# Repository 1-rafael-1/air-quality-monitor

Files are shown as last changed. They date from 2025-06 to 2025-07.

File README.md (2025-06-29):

# Air Quality Monitor

A compact, battery-powered air quality monitoring device built with Rust and a Waveshare RP2350-based board. This device continuously monitors air quality, temperature, and humidity with a small OLED display.

**⚠️ Educational Project Notice**: This is a hobby project developed for educational purposes only.

## Finished Device

<table>
<tr>
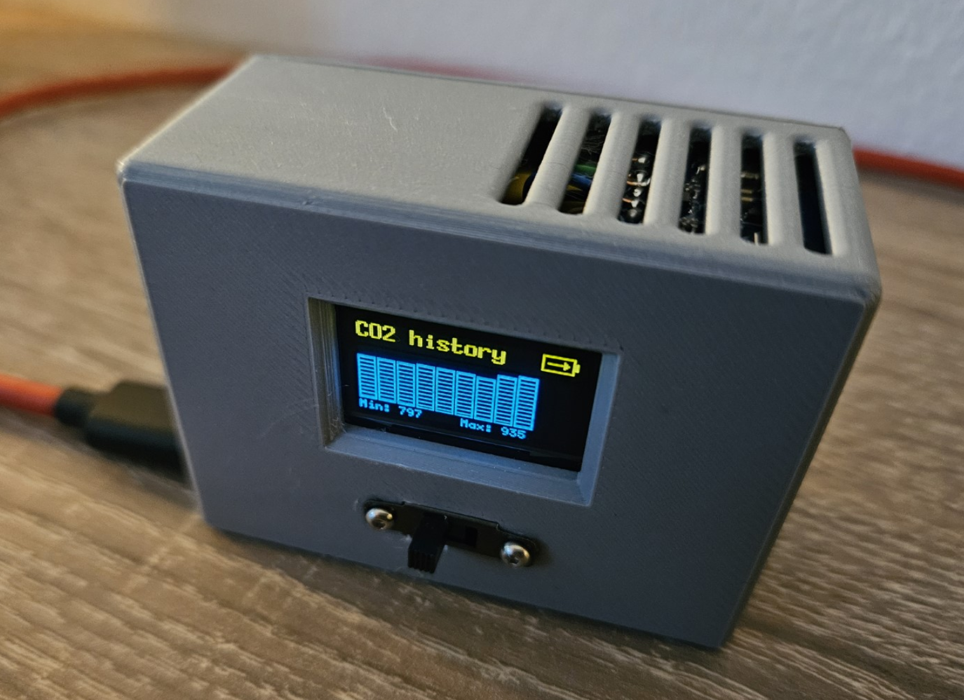
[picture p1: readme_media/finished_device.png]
Finished Air Quality Monitor Device
<td></td>
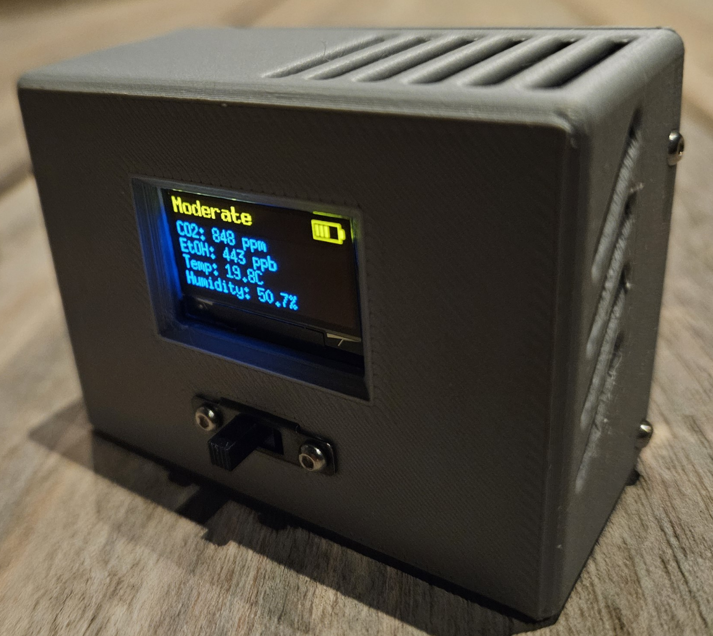
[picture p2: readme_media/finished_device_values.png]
Device Display Showing Values
<td></td>
</tr>
</table>

## How It Works

1. **Sensor Reading**: Collects data from ENS160 (air quality) and AHT21 (temperature/humidity) sensors every 5 minutes
2. **Data Processing**: Uses median filtering on air quality readings to reduce noise
3. **Display Updates**: Shows current readings and battery status on a 128x64 OLED display, changing between data and bar graph views every 10 seconds
4. **Power Management**: Reduced clock speed (18MHz) and core voltage to conserve power.
5. **Battery Monitoring**: VSYS voltage is measured every 4 seconds to determine battery level and charging state. Uses moving median filtering (5 samples) when on battery power for stable readings, and direct measurements when charging to reduce latency.

## Components

| Component | Description | Purpose |
|---|---|---|
| Waveshare RP2350 Board | RP2350-based development board. There are cheaper alternatives available on AliExpress, so long as they have the Pico 2 form factor and a battery connector with charger it should be fine | Core processing and I/O |
| ENS160 + AHT21 Module | Combined air quality and temperature/humidity sensor board. There are cheap combined boards available | Environmental monitoring |
| SSD1306 | 128x64 OLED Display, yellow/blue in my case here but monochrome or blue will work just as well | Data visualization |
| LiPo Battery | 3.7V rechargeable battery. I use 2500mAh, 7 x 40 x 60mm with a 1.25mm connector | Portable power source |
| Slide Switch | Slide switch to control power | Power management |

### Things to know

The ENS160 sensor and AHT21 sensor are on a combined board here, bought very cheap. An ENS160 datasheet and the ENS160 sensor on the board do not always agree on things. The AHT21 may in fact be an AHT20 according to some comments...

Here is what I found not being what I expected:

+ ENS160 ADD pin seems to be floating, sensor will not work if not connected to GND
+ Vendor says 1min warmup time, datasheet says 3min warmup time for ENS160.
+ ENS160 datasheet specifies `InitialStartupPhase` during the first 1 hour of operation and after 24h the sensor should save that it will never need this again. I find this not to be the case, that way all ideas of elaborate power management and sleep/wake cycles are out of the window. The sensor needs to be continuously powered to provide reliable readings.
+ AHT21 humidity is always reasonably close to external sensor readings, but temperature is always 2 to 3 degrees Celsius above external sensor readings. I just introduced a correction factor in code. I suppose this is due to the sensor being on the same board as the ENS160, which generates heat during operation.

Bottom line: You buy cheap, you get cheap.

## Hardware Connections

Connect the components to the Waveshare RP2350 board as follows:

### I2C Bus (Shared)

All I2C devices (ENS160 + AHT21 module and SSD1306 display) connect to the same I2C bus.
Since ENS160 and AHT21 are on the same module, they share the bus anyway and the SSD1306 display is also connected to the same I2C bus for simplicity.

### ENS160 + AHT21 Module

+ **VCC**: 3.3V
+ **GND**: Ground
+ **SDA**: GPIO 16
+ **SCL**: GPIO 17
+ **INT**: GPIO 18 (ENS160 interrupt pin)

### SSD1306 OLED Display

+ **VCC**: 3.3V
+ **GND**: Ground
+ **SDA**: GPIO 16
+ **SCL**: GPIO 17

### Power Monitoring

The Waveshare board has a battery connector, that is wired to vsys, so not need for connections beside plugging in the battery.

Power and charging detection is handled through VSYS voltage monitoring due to RP2350 E9 erratum affecting VBUS detection.

### Battery

+ **Battery**: 3.7V LiPo battery connected to the battery connector on the Waveshare board.

The Waveshare board has built-in battery charging and power management, so no additional components are required.
In case you want to use i.e. a Pi Pico 2, you need to add a charger board and appropriate circuit. The Pi Pico 2 datasheet has instructions.

## Power Consumption

On average I measure around 39mA current consumption when supplying 3.7V to the device (which is the nominal voltage for the battery I use).

The baseline for controller and display combined is around 10-11mA, the ENS160 sensor draws around 28mA when operating continuously in Standard mode, the AHT21 is negligible. With these values the device can theoretically run for around 65 hours on a 2500mAh battery, considering the built-in charge controller of the battery will not let us use more than say 90% of the battery capacity.

Sleep/wake cycling was initially attempted to reduce power consumption, but proved unreliable (see above).

## Assembly and Enclosure

### Electronics Assembly

Wire the components according to the hardware connections above. For the slide switch, cut the ground wire of the battery connector and connect it to the switch.

<table>
<tr>
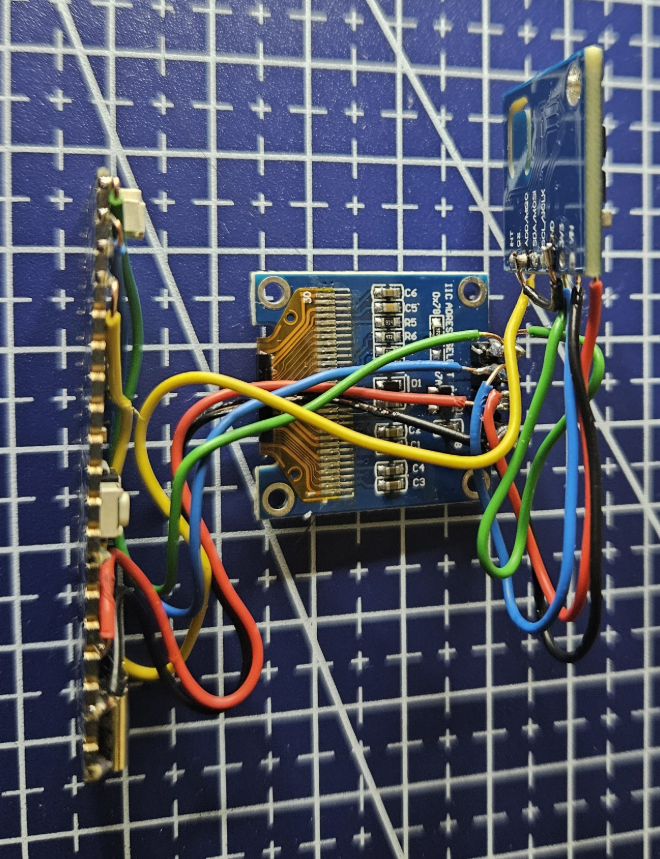
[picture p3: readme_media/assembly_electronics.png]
Electronics Assembly
<td></td>
</tr>
</table>

### 3D-Printed Enclosure

The device features a custom 3D-printed enclosure.

**3D Print Files**: All enclosure files are available in the [`enclosure/`](./enclosure/) directory:

+ `Main Body.3mf` - Main housing with sensor openings
+ `Back Lid.3mf` - Battery compartment cover
+ `EnclosureComplete.FCStd` - Body FreeCAD file
+ `Back Lid.FCStd` - Back lid FreeCAD file

<table>
<tr>
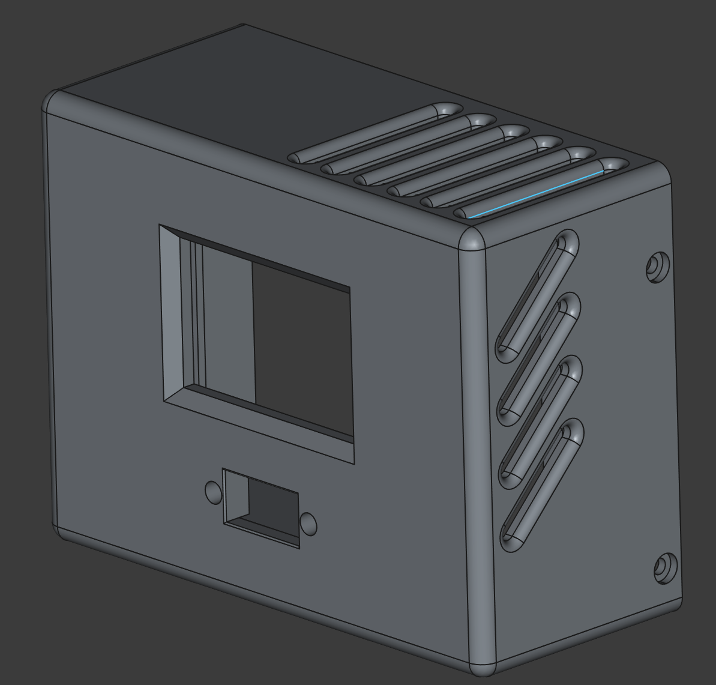
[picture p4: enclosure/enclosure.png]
3D Printed Enclosure
<td></td>
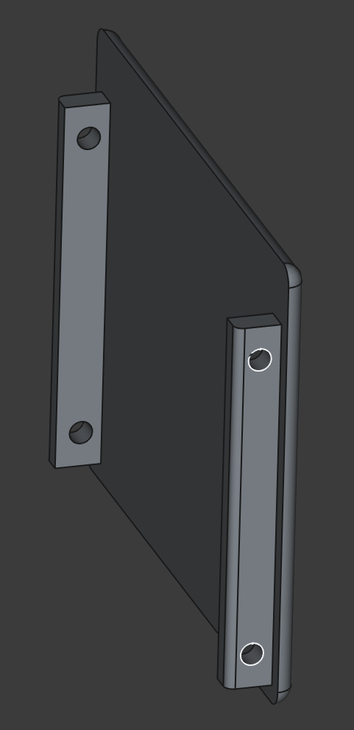
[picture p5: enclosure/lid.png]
Enclosure Lid Detail
<td></td>
</tr>
</table>

### Enclosure Assembly

After printing the enclosure parts, assemble the electronics into the housing. The main body provides openings for sensor airflow while protecting the internal components.

<table>
<tr>
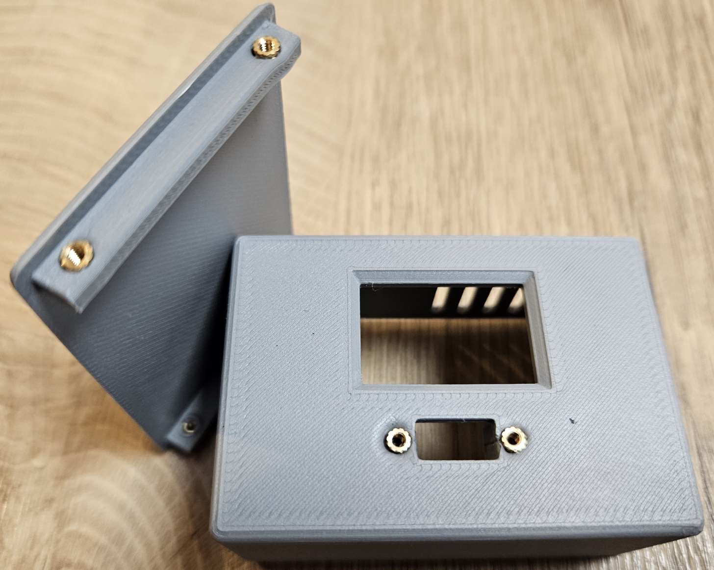
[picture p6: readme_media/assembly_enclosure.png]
Enclosure Assembly Process
<td></td>
</tr>
</table>

Use brass hot melt inserts for the enclosure screws to secure the back lid. Same goes for the slide switch, which is mounted on the front side of the enclosure.

The whole electronics can be fitted inside without any glue, only the OLED display needs held in place by tape (because i forgot to design a holder for it).

<table>
<tr>
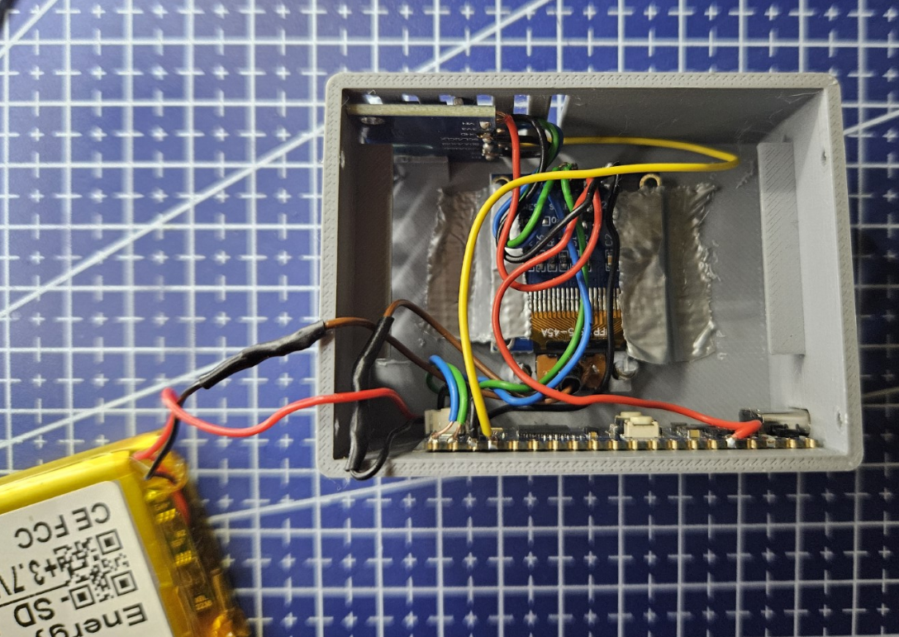
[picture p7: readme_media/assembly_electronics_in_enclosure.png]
Enclosure Assembly Process 2
<td></td>
</tr>
</table>

## Code Structure

The firmware is built using Embassy (async Rust) and organized into modular tasks:

```text
src/
├── main.rs          # Entry point, hardware initialization, task spawning
├── sensor.rs        # ENS160 and AHT21 sensor data acquisition
├── display.rs       # SSD1306 OLED display management and UI rendering
├── event.rs         # Inter-task communication events
├── orchestrate.rs   # Main control loop and data coordination
├── system_state.rs  # System state management (battery, sensor data, display modes)
├── vsys.rs          # Battery voltage monitoring and charging detection
├── watchdog.rs      # System watchdog
└── media/           # Bitmap assets for display (battery icons, etc.)
```

### Key Features

+ **Async Architecture**: Uses Embassy framework for task scheduling
+ **Power Optimization**: 18MHz clock, voltage scaling, and idle modes
+ **Median Filtering**: Reduces sensor noise through statistical processing
+ **Battery Monitoring**: VSYS-based voltage tracking with adaptive filtering (median filtering on battery, direct measurement when charging)
+ **Charging Detection**: Automatic detection of charging state via voltage thresholds (works around RP2350 E9 erratum)
+ **Mode Switching**: Automatic display cycling between sensor data and CO2 history views
+ **Watchdog System**: Monitors task health with 15-minute timeout and automatic system reset on failure

## Building and Flashing

```bash
# Build for release (optimized for size and power)
cargo build --release

# Option 1: Flash directly with picotool (elf2uf2-rs does not support RP2350 as of 06.2025)
# Put board in bootloader mode (hold BOOTSEL while connecting USB)
picotool load -u -v -x -t elf target/thumbv8m.main-none-eabihf/release/air-quality-monitor

# Option 2: Convert to UF2 and copy manually
picotool uf2 convert target/thumbv8m.main-none-eabihf/release/air-quality-monitor -t elf air-quality-monitor.uf2 -t uf2
# Copy the resulting .uf2 file to the RP2350 board in bootloader mode
```

For development builds probe-rs can be used:

```bash
# Build for development
cargo build
# Flash using probe-rs
cargo run
```

## License

This project is licensed under either of:

+ [Apache License, Version 2.0](LICENSE-APACHE)
+ [MIT License](LICENSE-MIT)

at your option.

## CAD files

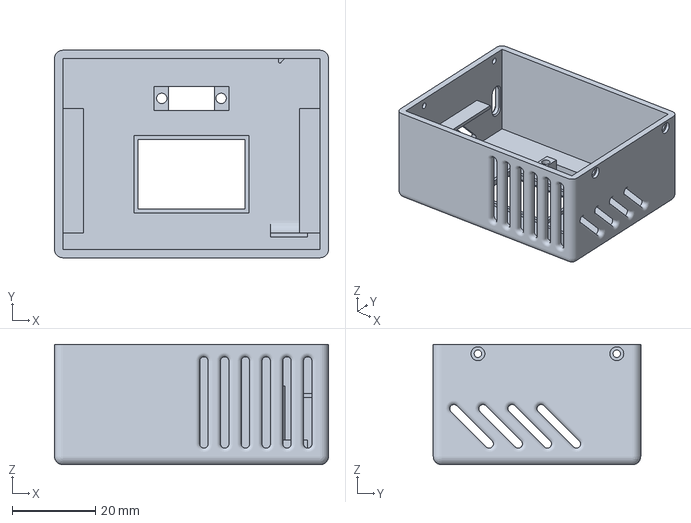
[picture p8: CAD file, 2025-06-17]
enclosure/Main Body.3mf
66.0 x 50.0 x 29.0 mm

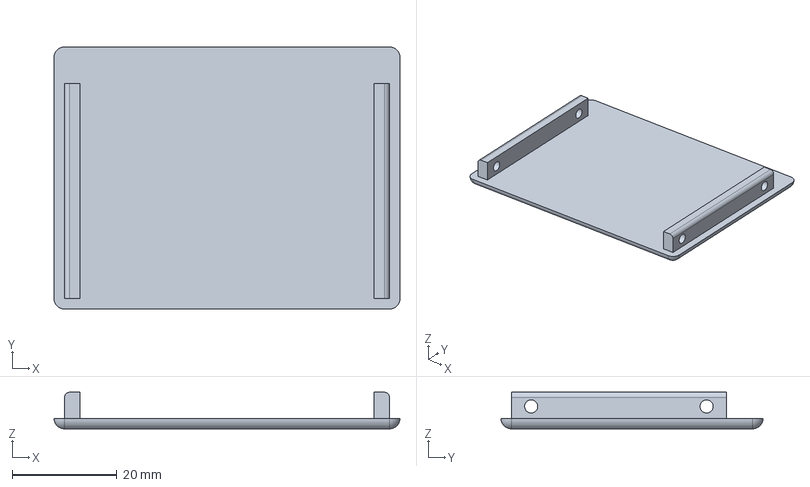
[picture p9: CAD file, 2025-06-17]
enclosure/Back Lid.FCStd
66.0 x 50.0 x 7.00 mm

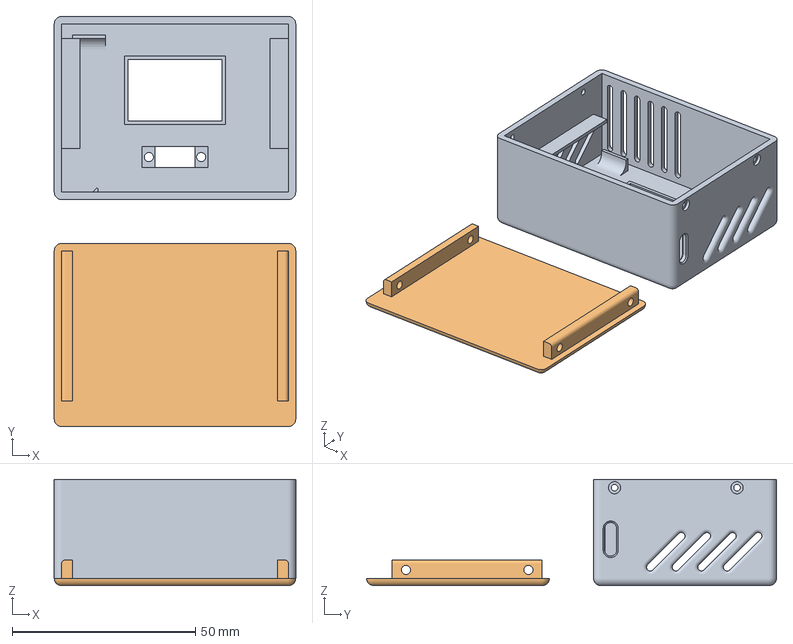
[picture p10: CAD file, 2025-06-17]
enclosure/Bambu Studio Print Project.3mf
66.0 x 112.0 x 29.0 mm

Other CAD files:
enclosure/EnclosureComplete.FCStd
enclosure/Back Lid.3mf

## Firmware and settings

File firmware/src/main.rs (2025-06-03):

#![no_std]
#![no_main]

use aht20_async::Aht20;
use defmt::{Debug2Format, info};
use defmt_rtt as _;
use embassy_embedded_hal::shared_bus::asynch::i2c::I2cDevice;
use embassy_executor::Spawner;
use embassy_rp::{
    bind_interrupts,
    block::ImageDef,
    config::Config,
    gpio::{Input, Pull},
    i2c::{Async, Config as I2cConfig, I2c, InterruptHandler},
    peripherals::{I2C0, PIN_18},
};
use embassy_sync::{blocking_mutex::raw::NoopRawMutex, mutex::Mutex};
use embassy_time::{Delay, Timer};
use ens160_aq::{
    Ens160,
    data::{InterruptPinConfig, OperationMode, ValidityFlag},
};
use panic_probe as _;
use static_cell::StaticCell;

// Firmware image type for bootloader
#[unsafe(link_section = ".start_block")]
#[used]
pub static IMAGE_DEF: ImageDef = ImageDef::secure_exe();

bind_interrupts!(struct Irqs {
        I2C0_IRQ => InterruptHandler<I2C0>;
    }
);

#[embassy_executor::main]
async fn main(_spawner: Spawner) {
    let p = embassy_rp::init(Config::default());

    // I2C setup
    let sda = p.PIN_16;
    let scl = p.PIN_17;
    let i2c0 = p.I2C0;
    let i2c = I2c::new_async(i2c0, scl, sda, Irqs, I2cConfig::default());
    static I2C_BUS: StaticCell<Mutex<NoopRawMutex, I2c<'static, I2C0, Async>>> = StaticCell::new();
    let i2c_bus = I2C_BUS.init(Mutex::new(i2c));
    let i2c_device_aht21 = I2cDevice::new(i2c_bus);
    let i2c_device_ens160 = I2cDevice::new(i2c_bus);

    // Initialize AHT20 and calibrate it
    let mut aht21 = Aht20::new(i2c_device_aht21, Delay).await.unwrap();
    info!("calibrate aht21");
    let _ = aht21.calibrate().await.unwrap();
    Timer::after_millis(5000).await;
    info!("done calibrating");

    // Initialize ENS160
    let mut ens160 = Ens160::new(i2c_device_ens160, Delay);
    let mut ens160_int = Input::new(p.PIN_18, Pull::Up);

    // In the loop, we read the AHT20 sensor and then use the ENS160 to get air quality data.
    loop {
        let (temp, rh) = {
            let (hum, temp) = aht21.read().await.unwrap();
            info!("Temperature: {}°C, Humidity: {}%", temp.celsius(), hum.rh());
            (temp.celsius(), hum.rh())
        };

        {
            match ens160.initialize().await {
                Ok(_) => {}
                Err(e) => {
                    info!("Failed to initialize ENS160: {}", Debug2Format(&e));
                    return;
                }
            };
            // ens160.clear_command().await.unwrap();
            ens160.set_operation_mode(OperationMode::Standard).await.unwrap();

            let mut status = ens160.get_status().await.unwrap();
            while !matches!(status.validity_flag(), ValidityFlag::NormalOperation) {
                info!("ENS160 is not in normal operation mode, waiting...");
                Timer::after_millis(1000).await;
                status = ens160.get_status().await.unwrap();
                info!("ENS160 status: {}", Debug2Format(&status));
            }

            ens160.set_temp_rh_comp(temp, rh as u16).await.unwrap();

            info!("ENS160 status: {}", Debug2Format(&status));

            let config = InterruptPinConfig::builder()
                .active_low()
                .enable_interrupt()
                .on_new_data()
                // .on_new_group_data()
                .build();

            info!("Configuring ENS160 interrupt pin: {}", config);

            ens160.config_interrupt_pin(config).await.unwrap();

            ens160.config_interrupt_pin(0x23).await.unwrap();
            Timer::after_millis(20).await;

            let status = ens160.get_status().await.unwrap();
            info!("ENS160 status: {}", Debug2Format(&status));

            // wait for ENS160 to have data ready
            info!("is low: {}", ens160_int.is_low());
            ens160_int.wait_for_low().await;
            info!("is low: {}", ens160_int.is_low());

            let status = ens160.get_status().await.unwrap();
            info!("ENS160 status: {}", Debug2Format(&status));

            // Timer::after_millis(1000).await;

            let eco2 = ens160.get_eco2().await.unwrap();
            let aq = ens160.get_airquality_index().await.unwrap();
            let h = ens160.get_etoh().await.unwrap();
            info!(
                "Air Quality Index: {}, eCO2: {} ppm, Ethanol: {} ppb",
                Debug2Format(&aq),
                eco2.get_value(),
                h,
            );
            ens160.set_operation_mode(OperationMode::Sleep).await.unwrap();
        } // drop ens160, but keep i2c_bus

        Timer::after_secs(10).await;
    }
}

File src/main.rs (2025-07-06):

//! RP2350 based air quality monitor firmware
//!
//! Uses ens160 for air quality, AHT21 for temperature and humidity, and SSD1306 for display.

#![no_std]
#![no_main]

/// Firmware version string
pub const FIRMWARE_VERSION: &str = concat!("v", env!("CARGO_PKG_VERSION"));

use defmt_rtt as _;
use embassy_embedded_hal::shared_bus::asynch::i2c::I2cDevice;
use embassy_executor::Spawner;
use embassy_rp::{
    adc::InterruptHandler as AdcInterruptHandler,
    bind_interrupts,
    block::ImageDef,
    clocks::{ClockConfig, CoreVoltage},
    config::Config,
    gpio::{Input, Pull},
    i2c::{Async, Config as I2cConfig, I2c, InterruptHandler},
    peripherals::I2C0,
};
use embassy_sync::{blocking_mutex::raw::NoopRawMutex, mutex::Mutex};
use panic_probe as _;
use static_cell::StaticCell;

mod display;
mod event;
mod humidity_calibrator;
mod orchestrate;
mod sensor;
mod system_state;
mod vsys;
mod watchdog;

// Firmware image type for bootloader
#[unsafe(link_section = ".start_block")]
#[used]
pub static IMAGE_DEF: ImageDef = ImageDef::secure_exe();

bind_interrupts!(struct Irqs {
        I2C0_IRQ => InterruptHandler<I2C0>;
        ADC_IRQ_FIFO => AdcInterruptHandler;
    }
);

#[embassy_executor::main]
async fn main(spawner: Spawner) {
    #[allow(clippy::unwrap_used)]
    // Reduce the clock speed to conserve power
    let mut config = Config::new(ClockConfig::system_freq(18_000_000).unwrap());
    config.clocks.core_voltage = CoreVoltage::V0_90;
    let p = embassy_rp::init(config);

    // I2C setup
    let sda = p.PIN_16;
    let scl = p.PIN_17;
    let i2c0 = p.I2C0;
    let i2c = I2c::new_async(i2c0, scl, sda, Irqs, I2cConfig::default());
    static I2C_BUS: StaticCell<Mutex<NoopRawMutex, I2c<'static, I2C0, Async>>> = StaticCell::new();
    let i2c_bus = I2C_BUS.init(Mutex::new(i2c));

    // Initialize the I2C devices
    let i2c_device_aht21 = I2cDevice::new(i2c_bus);
    let i2c_device_ens160 = I2cDevice::new(i2c_bus);
    let i2c_device_ssd1306 = I2cDevice::new(i2c_bus);

    // Initialize the interrupt pin for ENS160
    let ens160_int = Input::new(p.PIN_18, Pull::Up);

    // And spawn the tasks
    #[allow(clippy::unwrap_used)]
    spawner
        .spawn(sensor::sensor_task(i2c_device_aht21, i2c_device_ens160, ens160_int))
        .unwrap();
    #[allow(clippy::unwrap_used)]
    spawner.spawn(display::display_task(i2c_device_ssd1306)).unwrap();
    #[allow(clippy::unwrap_used)]
    spawner.spawn(display::mode_switch_task()).unwrap();
    #[allow(clippy::unwrap_used)]
    spawner.spawn(watchdog::watchdog_task(p.WATCHDOG)).unwrap();
    #[allow(clippy::unwrap_used)]
    spawner.spawn(orchestrate::orchestrate_task()).unwrap();
    #[allow(clippy::unwrap_used)]
    spawner.spawn(vsys::vsys_voltage_task(p.ADC, p.PIN_29)).unwrap();
}

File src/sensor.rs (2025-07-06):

//! Sensor task for reading data from AHT21 and ENS160 sensors.
use aht20_async::Aht20;
use defmt::{Debug2Format, info};
use embassy_embedded_hal::shared_bus::asynch::i2c::I2cDevice;
use embassy_rp::{
    gpio::Input,
    i2c::{Async, I2c},
    peripherals::I2C0,
};
use embassy_sync::blocking_mutex::raw::NoopRawMutex;
use embassy_time::{Delay, Timer};
use ens160_aq::{
    Ens160,
    data::{AirQualityIndex, InterruptPinConfig},
};
use heapless::Vec;
use moving_median::MovingMedian;
use panic_probe as _;

use crate::{
    event::{Event, send_event},
    humidity_calibrator::HumidityCalibrator,
    watchdog::{TaskId, report_task_failure, report_task_success},
};

/// Temperature offset for AHT21 sensor in degrees Celsius
static AHT21_TEMPERATURE_OFFSET: f32 = -3.5;

/// Warmup time for ENS160 sensor in seconds
const WARMUP_TIME: u64 = 180;

/// Read interval for continuous operation (5 minutes)
const READ_INTERVAL: u64 = 300;

/// Number of readings for ENS160 median calculation
const ENS160_MEDIAN_READINGS: usize = 3;

/// Initialize the AHT21 sensor
async fn initialize_aht21(
    aht21_device: I2cDevice<'static, NoopRawMutex, I2c<'static, I2C0, Async>>,
) -> Option<Aht20<I2cDevice<'static, NoopRawMutex, I2c<'static, I2C0, Async>>, Delay>> {
    let mut aht21 = Aht20::new(aht21_device, Delay).await.ok()?;
    Timer::after_millis(100).await;
    info!("calibrate aht21");
    aht21.calibrate().await.ok()?;
    info!("AHT21 calibration successful");
    Timer::after_millis(1000).await;
    Some(aht21)
}

/// Initialize the ENS160 sensor
async fn initialize_ens160(
    ens160_device: I2cDevice<'static, NoopRawMutex, I2c<'static, I2C0, Async>>,
) -> Option<Ens160<I2cDevice<'static, NoopRawMutex, I2c<'static, I2C0, Async>>, Delay>> {
    let mut ens160 = Ens160::new(ens160_device, Delay);

    if let Err(e) = ens160.initialize().await {
        info!(
            "Failed to initialize ENS160: {} - triggering system reset",
            Debug2Format(&e)
        );
        return None;
    }
    info!("ENS160 initialized successfully");

    Some(ens160)
}

/// Struct to hold AHT21 sensor readings
struct Aht21Readings {
    /// Raw temperature in degrees Celsius (for ENS160 compensation)
    raw_temperature: f32,
    /// Display temperature in degrees Celsius (with offset applied)
    display_temperature: f32,
    /// Raw humidity in percentage (uncalibrated)
    raw_humidity: f32,
    /// Calibrated humidity in percentage
    calibrated_humidity: f32,
}

/// Struct to hold ENS160 sensor readings
struct Ens160Readings {
    /// eCO2 level in ppm
    co2: f32,
    /// Ethanol (TVOC) level in ppb
    etoh: f32,
    /// Air quality index data
    air_quality: AirQualityIndex,
}

/// Read data from AHT21 sensor
async fn read_aht21(
    aht21: &mut Aht20<I2cDevice<'static, NoopRawMutex, I2c<'static, I2C0, Async>>, Delay>,
    humidity_calibrator: &mut HumidityCalibrator,
) -> Result<Aht21Readings, &'static str> {
    let (hum, temp) = aht21.read().await.map_err(|_| "Failed to read AHT21 sensor")?;
    let raw_temp = temp.celsius();
    let raw_rh = hum.rh();

    // Add measurement to calibrator for learning (this also detects rapid changes)
    humidity_calibrator.add_measurement(raw_temp, raw_rh);

    // Apply calibration (this preserves rapid changes while applying offset corrections)
    let calibrated_rh = humidity_calibrator.calibrate_humidity(raw_temp, raw_rh);

    let readings = Aht21Readings {
        raw_temperature: raw_temp,
        display_temperature: raw_temp + AHT21_TEMPERATURE_OFFSET,
        raw_humidity: raw_rh,
        calibrated_humidity: calibrated_rh,
    };

    let (is_calibrated, baseline_offset, statistical_offset, sample_count, in_rapid_change, long_term_count) =
        humidity_calibrator.get_calibration_info();
    let calibration_status = if !is_calibrated {
        "ESTABLISHING_BASELINE"
    } else if in_rapid_change {
        if humidity_calibrator.baseline_shifted {
            "BASELINE_SHIFT"
        } else {
            "RAPID_CHANGE"
        }
    } else {
        "HYBRID_DRIFT_CORRECTION"
    };

    info!(
        "Temperature: {}°C (raw: {}°C), Humidity: {}% -> {}% (raw->cal), Calibration: {} (baseline offset: {}, statistical offset: {}, samples: {}, long-term count: {})",
        readings.display_temperature,
        readings.raw_temperature,
        readings.raw_humidity,
        readings.calibrated_humidity,
        calibration_status,
        baseline_offset,
        statistical_offset,
        sample_count,
        long_term_count
    );

    Ok(readings)
}

/// Read data from ENS160 sensor
/// Uses moving median of 3 readings taken, using interrupt to ensure complete data
/// Note: Temperature and humidity compensation should be set separately using `set_ens160_compensation`
async fn read_ens160(
    ens160: &mut Ens160<I2cDevice<'static, NoopRawMutex, I2c<'static, I2C0, Async>>, Delay>,
    int: &mut Input<'static>,
) -> Result<Ens160Readings, &'static str> {
    let mut co2_median = MovingMedian::<f32, ENS160_MEDIAN_READINGS>::new();
    let mut etoh_median = MovingMedian::<f32, ENS160_MEDIAN_READINGS>::new();
    let mut co2_aqi_pairs: Vec<(f32, AirQualityIndex), ENS160_MEDIAN_READINGS> = Vec::new();

    for i in 0..ENS160_MEDIAN_READINGS {
        info!("ENS160 reading {} of {}", i + 1, ENS160_MEDIAN_READINGS);

        // Wait for interrupt to ensure sensor has new data ready
        int.wait_for_low().await;
        info!("ENS160 interrupt received - data ready");

        let status = ens160.get_status().await.map_err(|_| "Failed to get ENS160 status")?;
        info!("ENS160 status: {}", Debug2Format(&status));

        let eco2 = ens160.get_eco2().await.map_err(|_| "Failed to get eCO2")?;
        let etoh = ens160.get_etoh().await.map_err(|_| "Failed to get ethanol")?;
        let aq = ens160
            .get_airquality_index()
            .await
            .map_err(|_| "Failed to get Air Quality Index")?;

        let co2_value = f32::from(eco2.get_value());
        let etoh_value = f32::from(etoh);

        info!(
            "Reading {}: Air Quality Index: {}, eCO2: {} ppm, Ethanol: {} ppb",
            i + 1,
            Debug2Format(&aq),
            co2_value,
            etoh_value
        );

        co2_median.add_value(co2_value);
        etoh_median.add_value(etoh_value);
        let _ = co2_aqi_pairs.push((co2_value, aq));
    }

    let median_co2 = co2_median.median();

    // Find the AQI that corresponds to the CO2 value closest to the median
    let air_quality = co2_aqi_pairs
        .iter()
        .min_by(|(co2_a, _), (co2_b, _)| {
            let diff_a = (co2_a - median_co2).abs();
            let diff_b = (co2_b - median_co2).abs();
            diff_a.partial_cmp(&diff_b).unwrap_or(core::cmp::Ordering::Equal)
        })
        .map(|(_, aqi)| *aqi)
        .ok_or("No CO2-AQI pairs available")?;
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

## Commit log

2025-05-29 i2c perm initialized
2025-06-03 initial stuff
    [Enclosure-Body.3mf, Enclosure-Bottom.3mf, Enclosure-Lid.3mf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]
2025-06-07 refactor: enhance project structure and documentation
    - Updated Cargo.toml with new metadata including name, authors, description, license, repository, keywords, and categories.
    - Added README.md for project overview.
    - Improved settings for rust-analyzer and added Clippy command.
    - Refactored display and event handling logic for better clarity
    - Enhanced sensor initialization and error handling.
    - Updated VBUS and VSYS tasks with improved logging and structure.
    - Introduced new sensor data handling and display drawing methods.
    [display.rs, main.rs, sensor.rs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]
2025-06-09 enhance display functionality with initialization message and improve voltage measurement handling
2025-06-09 remove ValidityFlag usage and improve sensor handling
2025-06-09 refactor: streamline sensor and voltage measurement handling
2025-06-11 refactor: improve sensor data handling and structure
2025-06-11 adjust AHT21 temperature reading with offset and simplify ENS160 data handling by no longer using a median filter
    [sensor.rs]
2025-06-11 update ENS160 sensor handling with improved idle and warmup logic
2025-06-14 v2 of the enclosure
    [Back Lid.3mf, Back Lid.FCStd, Bambu Studio Print Project.3mf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]
2025-06-16 Update configuration, add licenses, enhance README, and include enclosure images
2025-06-16 Refactor enclosure files: remove outdated backups and update project files
    [Back Lid.FCStd, Bambu Studio Print Project.3mf, EnclosureComplete.FCStd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]
2025-06-16 Refactor display handling: replace Signal with Channel for state updates and update related async functions
    [display.rs, main.rs, vsys.rs]
2025-06-17 Update enclosure files: modify 3D models and images, remove outdated backup
    [Back Lid.3mf, Back Lid.FCStd, Bambu Studio Print Project.3mf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]
2025-06-17 Refactor README: update enclosure images to use table format for better layout
2025-06-19 Update README: enhance documentation with new images and detailed assembly instructions
2025-06-21 Refactor display and system state management: consolidate display state handling, update battery monitoring logic, and remove VBUS monitoring
2025-06-21 Refactor display task and event handling: replace shared state with global SYSTEM_STATE, update event system to include display mode toggle, and enhance sensor data management
    [display.rs, main.rs]
2025-06-21 Refactor display and system health management: replace watchdog reset calls with task success/failure reporting, consolidate display state handling, and enhance task health tracking
    [display.rs, sensor.rs, vsys.rs]
2025-06-21 display rendering: replace solid fill with hatched bars to reduce power consumption
    [display.rs]
2025-06-21 Update README and sensor logic: revise ENS160 warmup time to 60 seconds, enhance documentation on sensor behavior, and add power consumption details.
2025-06-21 Update README: correct power consumption values and fix typos in sensor descriptions
2025-06-23 Enhance sensor state management: add ENS160 calibration state tracking and related methods for initialization, marking completion, and resetting calibration status.
    [sensor.rs]
2025-06-23 Update display message: change "Initializing sensors" to "Warming up sensors"
2025-06-23 Fix AHT21 temperature offset
    [sensor.rs]
2025-06-23 Enhance VSYS voltage task: track previous charging state and battery percentage to reduce event spam
2025-06-23 Fix AHT21 temperature offset and adjust idle time handling in sensor task
    [sensor.rs]
2025-06-24 Refactor sensor initialization and reading loop: extract init and loop into fn and only wake in calibrated state.
2025-06-24 Update sensor task logging and adjust watchdog health check interval
2025-06-24 Update README and sensor code to clarify sensor calibration and idle mode handling
2025-06-26 Update watchdog timer settings and simplify task health reporting
2025-06-26 Refactor sensor code: remove ENS160 idle/wake cycle logic and calibration state management because the s#|7 does not work as described in the datasheet.
    [sensor.rs]
2025-06-26 Update README to correct sensor reading interval and clarify power management details
2025-06-29 Update AHT21 temperature offset to improve accuracy
2025-06-29 Adjust VSYS voltage offset and update maximum voltage for battery percentage calculation
2025-06-29 Update README with assembly instructions and add enclosure assembly image; remove outdated power profile image
2025-06-29 Update finished device image in README media
2025-07-06 humidity self-calibration (#1)
    * use actual temp on sensor for compensation, keep displaying offset temp
    * Refactor display task initialization and command handling, clippy warning
    * Implement humidity calibration system with statistical analysis and outlier detection
    * Bump version to 0.3.0 and enhance sensor data display with raw values for temperature and humidity
    * earlier correction
    * Update air quality monitor firmware binary
    * caching for statistical results to improve performance
    * removing unused runtime hours tracking
    * Add humidity calibration module
    * Update air quality monitor firmware binary
    [display.rs, main.rs, sensor.rs]
